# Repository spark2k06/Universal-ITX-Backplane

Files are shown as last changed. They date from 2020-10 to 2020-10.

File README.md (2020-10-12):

# Universal ITX BackPlane

This backplane is initially intended to be used with Sergey Kiselev's Micro8088 or xi8088 PC clones, among others system powered by x86 architecture. However, other old systems could also be developed using FPGAs built or adapted to ISA or PC / 104 type slots, plus other accessories based on these.

More information of this project in my Hackaday account: https://hackaday.io/project/175340-universal-itx-backplane

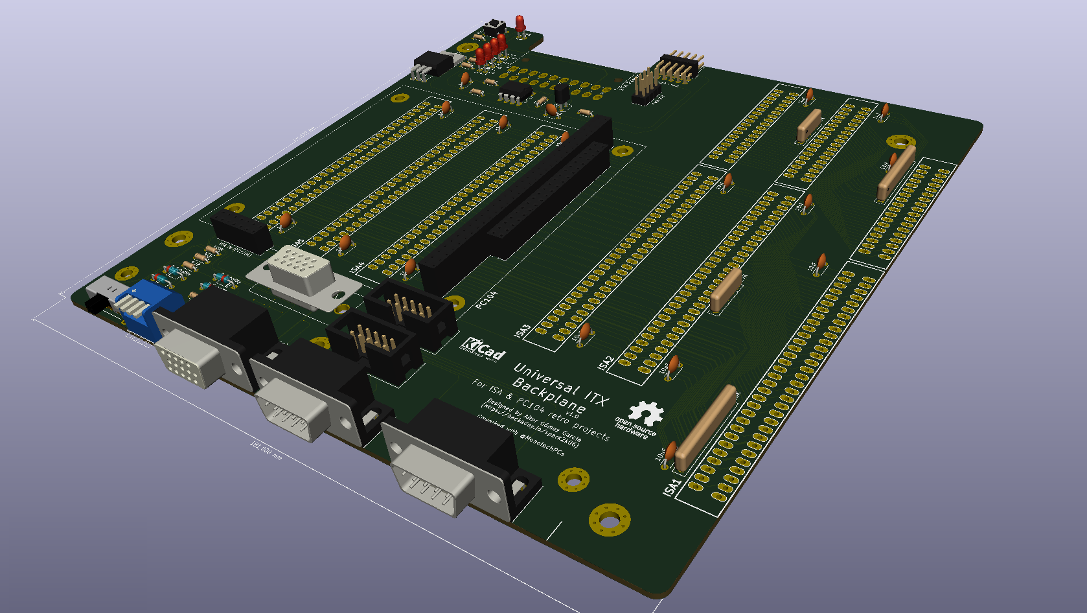
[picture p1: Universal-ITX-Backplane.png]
Jumpers


The PCB has several I / O connectors common to all projects:

* VGA + MonochromeVGA integrated
* 2 x DB9 ports to be used as serial ports or as joysticks

Additionally, each project can also add a Hat I / O board by adding other specific connectors. For example, an old PC based on a PC / 104 slot could add PS / 2 ports, IDE44 2.0mm connector to connect an external HD or CF, etc ... it must be taken into account that internally the Hat I / O board does not have of a lot of space, several holes have been placed to fasten it to the backplane.

Notice: The project is still in the prototype phase, the first version has not yet been tested.

# Version 1.0

First version of project

Coworked with @MonotechPCs (Twitter profile)

* 4 Layer Mini-ITX board
* 3 x ISA 8 / 16 bits slots
* 1 x PC104 8 / 16 bits slot
* 3 x ISA 8 bits slots
* I/O shield with MonochromeVGA integrated, VGA, and 2 x DB9 connectors

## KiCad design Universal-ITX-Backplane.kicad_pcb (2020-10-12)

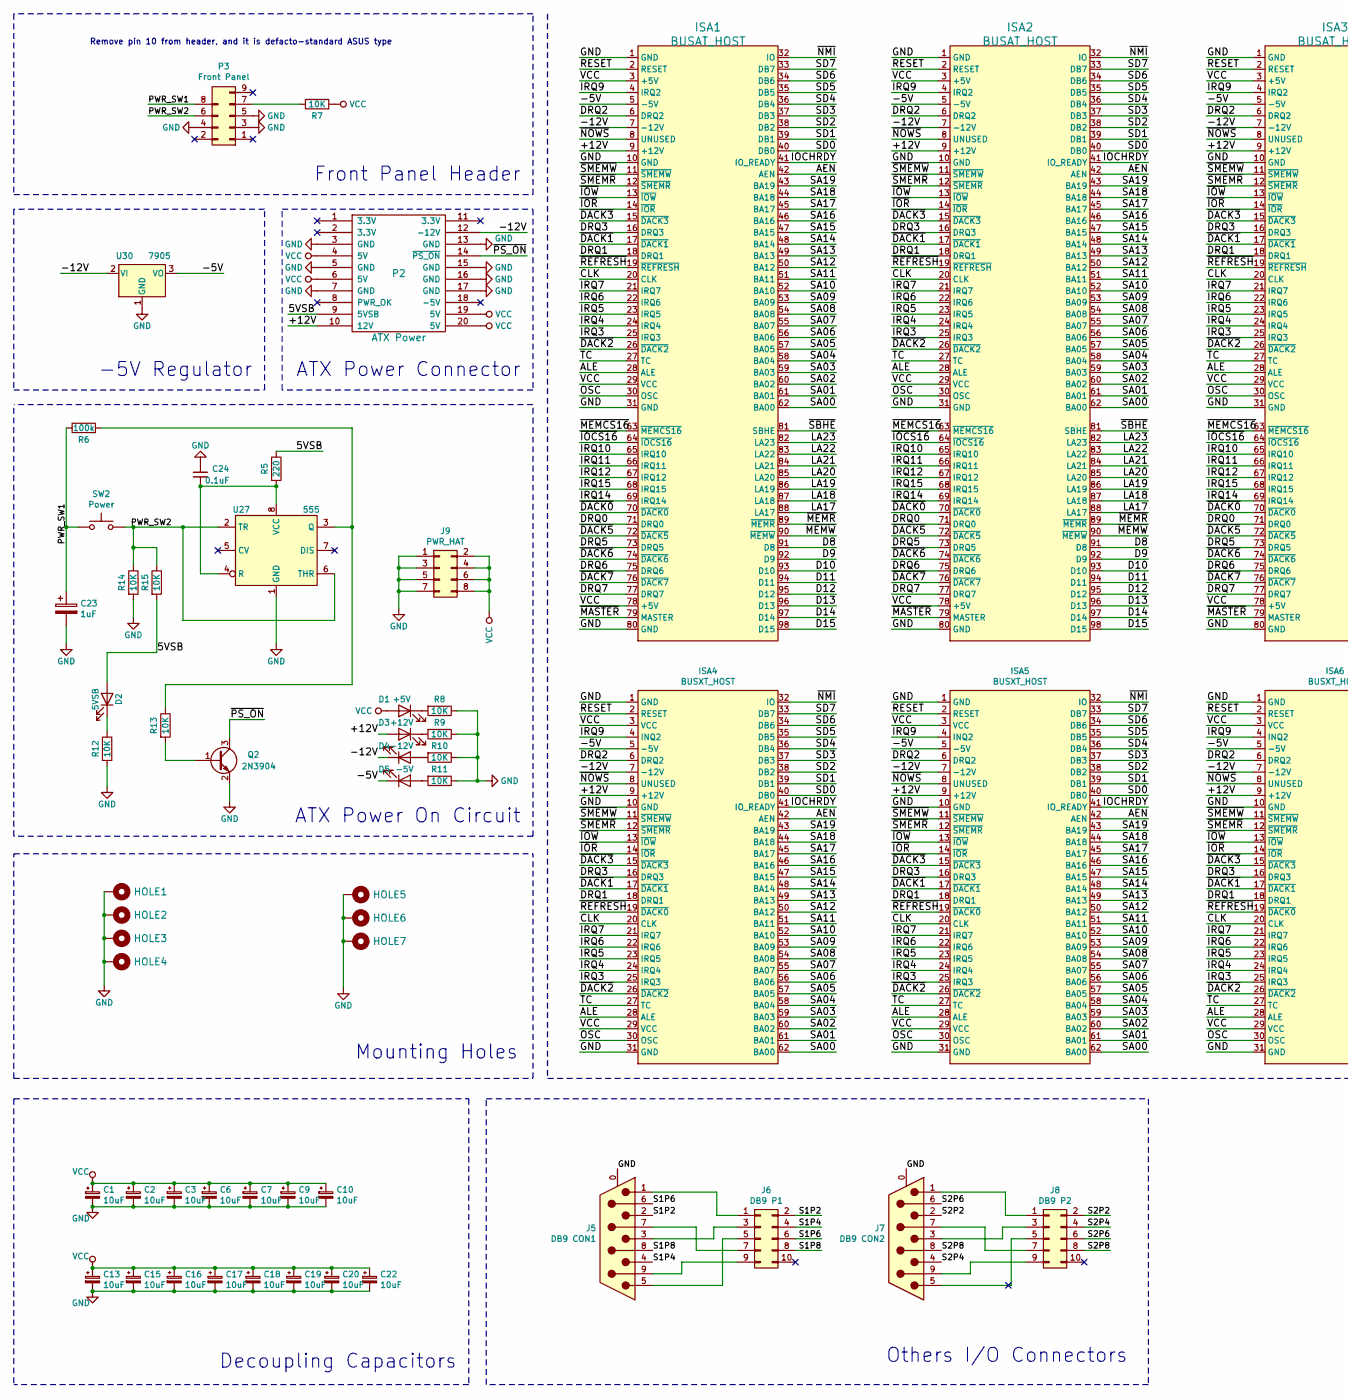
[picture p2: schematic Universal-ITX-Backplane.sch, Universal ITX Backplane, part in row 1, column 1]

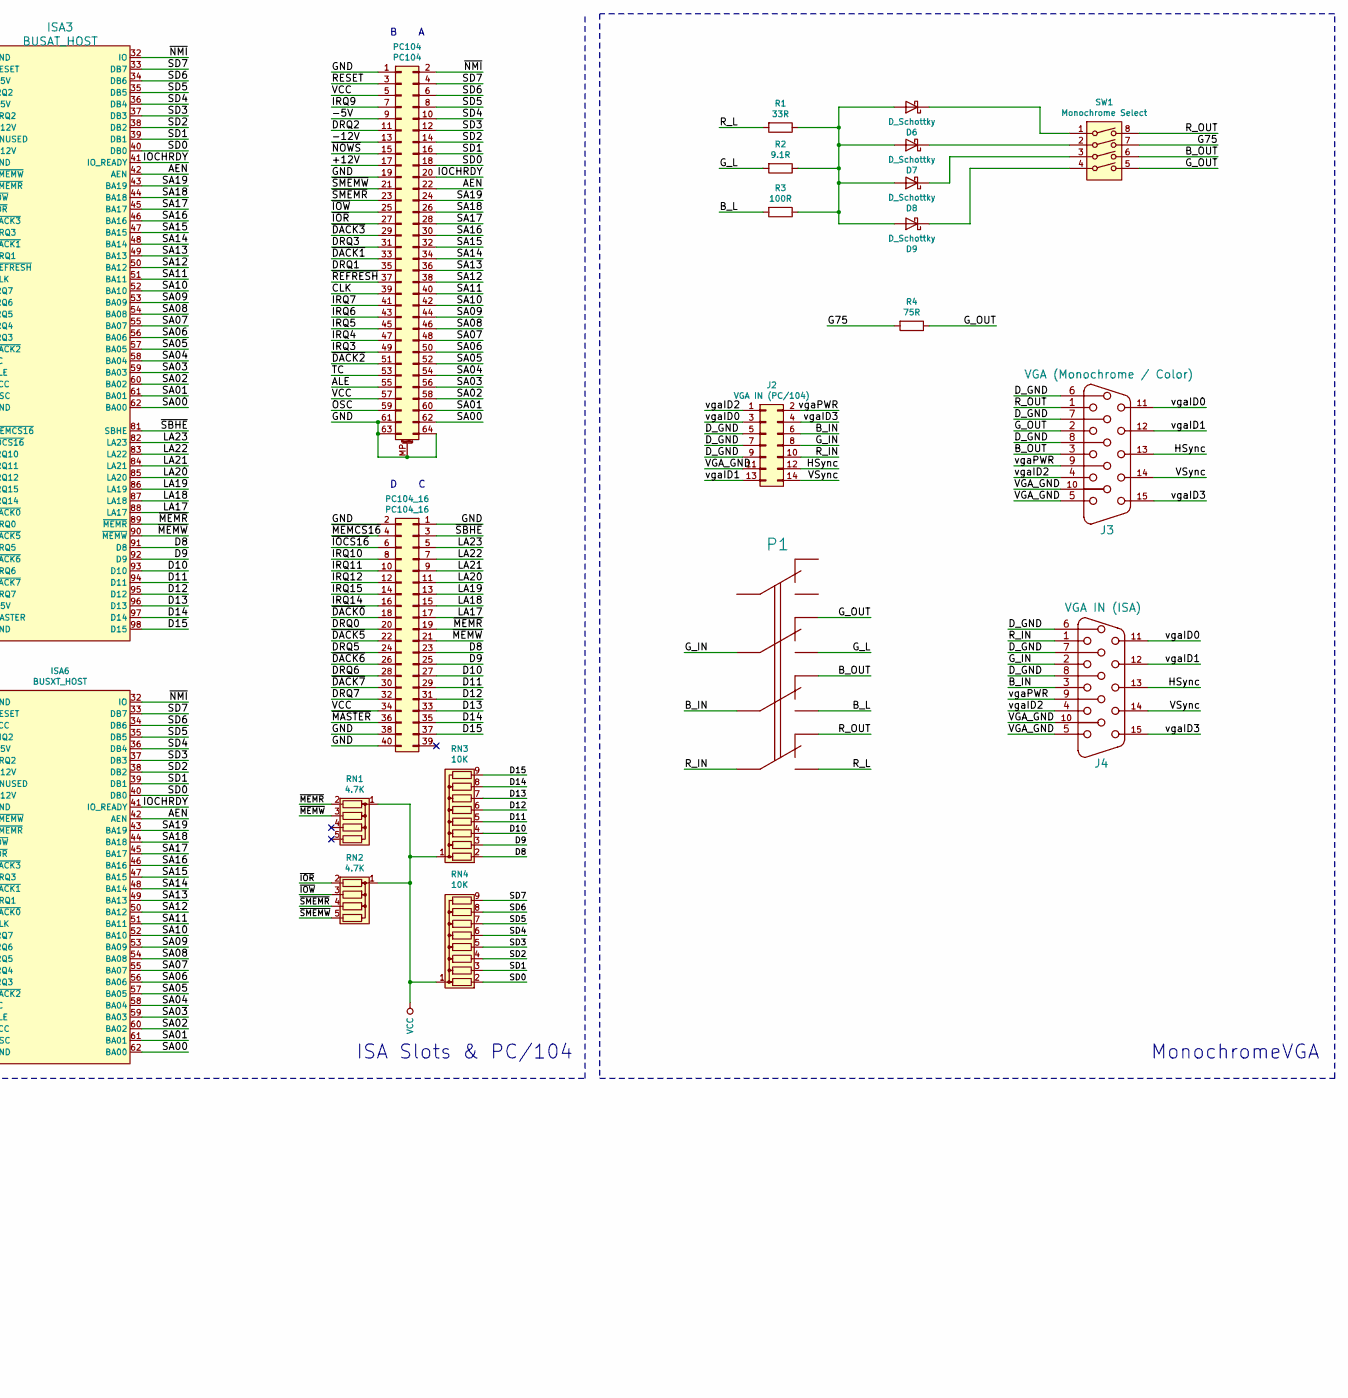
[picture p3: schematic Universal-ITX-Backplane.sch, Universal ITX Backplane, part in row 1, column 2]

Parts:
C1, C2, C3, C6, C7, C9, C10, C13, C15, C16, C17, C18, C19, C20, C22: 10uF; C_Disc_D4.3mm_W1.9mm_P5.00mm; LCSC P# C19702
C23: 1uF; C_Disc_D4.3mm_W1.9mm_P5.00mm; LCSC P# C28323
C24: 0.1uF; C_Disc_D4.3mm_W1.9mm_P5.00mm; LCSC P# C14663
D1: +5V; LED_D3.0mm; LCSC P# C84256
D2: 5VSB; LED_D3.0mm; LCSC P# C84256
D3: +12V; LED_D3.0mm; LCSC P# C84256
D4: -12V; LED_D3.0mm; LCSC P# C84256
D5: -5V; LED_D3.0mm; LCSC P# C84256
D6, D7, D8, D9: D_Schottky; D_DO-35_SOD27_P7.62mm_Horizontal
HOLE1, HOLE2, HOLE3, HOLE4: HOLE; MountingHole_4mm_Pad_Via
HOLE5, HOLE6, HOLE7: HOLE; MountingHole_3.2mm_M3_Pad_Via
ISA1, ISA2, ISA3: BUSAT_HOST; ISA16
ISA4, ISA5, ISA6: BUSXT_HOST; Conn_Edge_ISA8_Longpads
J2: VGA IN (PC/104); PinSocket_2x07_P2.54mm_Vertical
J3: VGA (Monochrome / Color); DSUB-15-HD_Female_Horizontal_P2.29x1.98mm_EdgePinOffset8.35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
J4: VGA IN (ISA); DSUB-15-HD_Female_Vertical_P2.29x1.98mm_MountingHoles
J5: DB9 CON1; DSUB-9_Male_Horizontal_P2.77x2.84mm_EdgePinOffset4.94mm_Hou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
J6: DB9 P1; IDC-Header_2x05_P2.54mm_Vertical
J7: DB9 CON2; DSUB-9_Male_Horizontal_P2.77x2.84mm_EdgePinOffset4.94mm_Hou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
J8: DB9 P2; IDC-Header_2x05_P2.54mm_Vertical
J9: PWR_HAT; PinHeader_2x04_P2.54mm_Vertical
P1: MONO <-> COLOR; SW-SK-42D01-G
P2: ATX Power; Molex_Mini-Fit_Jr_5569-20A2_2x10_P4.20mm_Horizontal
P3: Front Panel; PinHeader_2x05_P2.54mm_Horizontal
PC104: PC104; PC104_Platform
PC104_16: PC104_16; PinSocket_2x20_P2.54mm_Vertical
Q2: 2N3904; TO-92; LCSC P# C20526
R1: 33R; R_Axial_DIN0204_L3.6mm_D1.6mm_P5.08mm_Horizontal
R2: 9.1R; R_Axial_DIN0204_L3.6mm_D1.6mm_P5.08mm_Horizontal
R3: 100R; R_Axial_DIN0204_L3.6mm_D1.6mm_P5.08mm_Horizontal
R4: 75R; R_Axial_DIN0204_L3.6mm_D1.6mm_P5.08mm_Horizontal
R5: 220; R_Axial_DIN0204_L3.6mm_D1.6mm_P5.08mm_Horizontal; LCSC P# C17407
R6: 100k; R_Axial_DIN0204_L3.6mm_D1.6mm_P5.08mm_Horizontal; LCSC P# C17407
R7: 10K; R_Axial_DIN0204_L3.6mm_D1.6mm_P5.08mm_Horizontal
R8, R9, R10, R11, R12, R13, R14, R15: 10K; R_Axial_DIN0204_L3.6mm_D1.6mm_P5.08mm_Horizontal; LCSC P# C17407
RN1, RN2: 4.7K; R_Array_SIP5
RN3, RN4: 10K; R_Array_SIP9
SW1: Monochrome Select; SW_DIP_SPSTx04_Piano_10.8x11.72mm_W7.62mm_P2.54mm
SW2: Power; SW_PUSH_6mm; LCSC P# C128536
U27: 555; DIP-8_W7.62mm_LongPads; LCSC P# C7593
U30: 7905; TO220-3_Soldertab; LCSC P# C75505

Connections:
/5VSB: D2.2 (A), P2.9 (5VSB), R5.1, R15.2
/+12V: D3.2 (A), ISA1.9 (+12V), ISA2.9 (+12V), ISA3.9 (+12V), ISA4.9 (+12V), ISA5.9 (+12V), ISA6.9 (+12V), P2.10 (12V), PC104.17
/-5V: D5.1 (K), ISA1.5 (-5V), ISA2.5 (-5V), ISA3.5 (-5V), ISA4.5 (-5V), ISA5.5 (-5V), ISA6.5 (-5V), PC104.9, U30.3 (VO)
/-12V: D4.1 (K), ISA1.7 (-12V), ISA2.7 (-12V), ISA3.7 (-12V), ISA4.7 (-12V), ISA5.7 (-12V), ISA6.7 (-12V), P2.12 (-12V), PC104.13, U30.2 (VI)
/AEN: ISA1.42 (AEN), ISA2.42 (AEN), ISA3.42 (AEN), ISA4.42 (AEN), ISA5.42 (AEN), ISA6.42 (AEN), PC104.22
/ALE: ISA1.28 (ALE), ISA2.28 (ALE), ISA3.28 (ALE), ISA4.28 (ALE), ISA5.28 (ALE), ISA6.28 (ALE), PC104.55
/B_IN: J2.6, J4.3, P1.8
/B_L: P1.9, R3.2
/B_OUT: J3.3, P1.7, SW1.6
/CLK: ISA1.20 (CLK), ISA2.20 (CLK), ISA3.20 (CLK), ISA4.20 (CLK), ISA5.20 (CLK), ISA6.20 (CLK), PC104.39
/D8: ISA1.91 (D8), ISA2.91 (D8), ISA3.91 (D8), PC104_16.23, RN3.2 (R1)
/D9: ISA1.92 (D9), ISA2.92 (D9), ISA3.92 (D9), PC104_16.25, RN3.3 (R2)
/D10: ISA1.93 (D10), ISA2.93 (D10), ISA3.93 (D10), PC104_16.27, RN3.4 (R3)
/D11: ISA1.94 (D11), ISA2.94 (D11), ISA3.94 (D11), PC104_16.29, RN3.5 (R4)
/D12: ISA1.95 (D12), ISA2.95 (D12), ISA3.95 (D12), PC104_16.31, RN3.6 (R5)
/D13: ISA1.96 (D13), ISA2.96 (D13), ISA3.96 (D13), PC104_16.33, RN3.7 (R6)
/D14: ISA1.97 (D14), ISA2.97 (D14), ISA3.97 (D14), PC104_16.35, RN3.8 (R7)
/D15: ISA1.98 (D15), ISA2.98 (D15), ISA3.98 (D15), PC104_16.37, RN3.9 (R8)
/DRQ0: ISA1.71 (DRQ0), ISA2.71 (DRQ0), ISA3.71 (DRQ0), PC104_16.20
/DRQ1: ISA1.18 (DRQ1), ISA2.18 (DRQ1), ISA3.18 (DRQ1), ISA4.18 (DRQ1), ISA5.18 (DRQ1), ISA6.18 (DRQ1), PC104.35
/DRQ2: ISA1.6 (DRQ2), ISA2.6 (DRQ2), ISA3.6 (DRQ2), ISA4.6 (DRQ2), ISA5.6 (DRQ2), ISA6.6 (DRQ2), PC104.11
/DRQ3: ISA1.16 (DRQ3), ISA2.16 (DRQ3), ISA3.16 (DRQ3), ISA4.16 (DRQ3), ISA5.16 (DRQ3), ISA6.16 (DRQ3), PC104.31
/DRQ5: ISA1.73 (DRQ5), ISA2.73 (DRQ5), ISA3.73 (DRQ5), PC104_16.24
/DRQ6: ISA1.75 (DRQ6), ISA2.75 (DRQ6), ISA3.75 (DRQ6), PC104_16.28
/DRQ7: ISA1.77 (DRQ7), ISA2.77 (DRQ7), ISA3.77 (DRQ7), PC104_16.32
/D_GND: J2.5, J2.7, J2.9, J3.6, J3.7, J3.8, J4.6, J4.7, J4.8
/G75: R4.2, SW1.7
/G_IN: J2.8, J4.2, P1.5
/G_L: P1.6, R2.2
/G_OUT: J3.2, P1.4, R4.1, SW1.5
/HSync: J2.12, J3.13, J4.13
/IOCHRDY: ISA1.41 (IO_READY), ISA2.41 (IO_READY), ISA3.41 (IO_READY), ISA4.41 (IO_READY), ISA5.41 (IO_READY), ISA6.41 (IO_READY), PC104.20
/IRQ3: ISA1.25 (IRQ3), ISA2.25 (IRQ3), ISA3.25 (IRQ3), ISA4.25 (IRQ3), ISA5.25 (IRQ3), ISA6.25 (IRQ3), PC104.49
/IRQ4: ISA1.24 (IRQ4), ISA2.24 (IRQ4), ISA3.24 (IRQ4), ISA4.24 (IRQ4), ISA5.24 (IRQ4), ISA6.24 (IRQ4), PC104.47
/IRQ5: ISA1.23 (IRQ5), ISA2.23 (IRQ5), ISA3.23 (IRQ5), ISA4.23 (IRQ5), ISA5.23 (IRQ5), ISA6.23 (IRQ5), PC104.45
/IRQ6: ISA1.22 (IRQ6), ISA2.22 (IRQ6), ISA3.22 (IRQ6), ISA4.22 (IRQ6), ISA5.22 (IRQ6), ISA6.22 (IRQ6), PC104.43
/IRQ7: ISA1.21 (IRQ7), ISA2.21 (IRQ7), ISA3.21 (IRQ7), ISA4.21 (IRQ7), ISA5.21 (IRQ7), ISA6.21 (IRQ7), PC104.41
/IRQ9: ISA1.4 (IRQ2), ISA2.4 (IRQ2), ISA3.4 (IRQ2), ISA4.4 (INQ2), ISA5.4 (INQ2), ISA6.4 (INQ2), PC104.7
/IRQ10: ISA1.65 (IRQ10), ISA2.65 (IRQ10), ISA3.65 (IRQ10), PC104_16.8
/IRQ11: ISA1.66 (IRQ11), ISA2.66 (IRQ11), ISA3.66 (IRQ11), PC104_16.10
/IRQ12: ISA1.67 (IRQ12), ISA2.67 (IRQ12), ISA3.67 (IRQ12), PC104_16.12
/IRQ14: ISA1.69 (IRQ14), ISA2.69 (IRQ14), ISA3.69 (IRQ14), PC104_16.16
/IRQ15: ISA1.68 (IRQ15), ISA2.68 (IRQ15), ISA3.68 (IRQ15), PC104_16.14
/LA17: ISA1.88 (LA17), ISA2.88 (LA17), ISA3.88 (LA17), PC104_16.17
/LA18: ISA1.87 (LA18), ISA2.87 (LA18), ISA3.87 (LA18), PC104_16.15
/LA19: ISA1.86 (LA19), ISA2.86 (LA19), ISA3.86 (LA19), PC104_16.13
/LA20: ISA1.85 (LA20), ISA2.85 (LA20), ISA3.85 (LA20), PC104_16.11
/LA21: ISA1.84 (LA21), ISA2.84 (LA21), ISA3.84 (LA21), PC104_16.9
/LA22: ISA1.83 (LA22), ISA2.83 (LA22), ISA3.83 (LA22), PC104_16.7
/LA23: ISA1.82 (LA23), ISA2.82 (LA23), ISA3.82 (LA23), PC104_16.5
/OSC: ISA1.30 (OSC), ISA2.30 (OSC), ISA3.30 (OSC), ISA4.30 (OSC), ISA5.30 (OSC), ISA6.30 (OSC), PC104.59
/PWR_SW1: C23.1, P3.8, R6.1, SW2.1
/PWR_SW2: P3.6, R14.1, R15.1, SW2.2, U27.2 (TR), U27.6 (THR)
/RESET: ISA1.2 (RESET), ISA2.2 (RESET), ISA3.2 (RESET), ISA4.2 (RESET), ISA5.2 (RESET), ISA6.2 (RESET), PC104.3
/R_IN: J2.10, J4.1, P1.11
/R_L: P1.12, R1.2
/R_OUT: J3.1, P1.10, SW1.8
/S1P2: J5.2, J6.2
/S1P4: J5.4, J6.4
/S1P6: J5.6, J6.6
/S1P8: J5.8, J6.8
/S2P2: J7.2, J8.2
/S2P4: J7.4, J8.4
/S2P6: J7.6, J8.6
/S2P8: J7.8, J8.8
/SA00: ISA1.62 (BA00), ISA2.62 (BA00), ISA3.62 (BA00), ISA4.62 (BA00), ISA5.62 (BA00), ISA6.62 (BA00), PC104.62
/SA01: ISA1.61 (BA01), ISA2.61 (BA01), ISA3.61 (BA01), ISA4.61 (BA01), ISA5.61 (BA01), ISA6.61 (BA01), PC104.60
/SA02: ISA1.60 (BA02), ISA2.60 (BA02), ISA3.60 (BA02), ISA4.60 (BA02), ISA5.60 (BA02), ISA6.60 (BA02), PC104.58
/SA03: ISA1.59 (BA03), ISA2.59 (BA03), ISA3.59 (BA03), ISA4.59 (BA03), ISA5.59 (BA03), ISA6.59 (BA03), PC104.56
/SA04: ISA1.58 (BA04), ISA2.58 (BA04), ISA3.58 (BA04), ISA4.58 (BA04), ISA5.58 (BA04), ISA6.58 (BA04), PC104.54
/SA05: ISA1.57 (BA05), ISA2.57 (BA05), ISA3.57 (BA05), ISA4.57 (BA05), ISA5.57 (BA05), ISA6.57 (BA05), PC104.52
/SA06: ISA1.56 (BA06), ISA2.56 (BA06), ISA3.56 (BA06), ISA4.56 (BA06), ISA5.56 (BA06), ISA6.56 (BA06), PC104.50
/SA07: ISA1.55 (BA07), ISA2.55 (BA07), ISA3.55 (BA07), ISA4.55 (BA07), ISA5.55 (BA07), ISA6.55 (BA07), PC104.48
/SA08: ISA1.54 (BA08), ISA2.54 (BA08), ISA3.54 (BA08), ISA4.54 (BA08), ISA5.54 (BA08), ISA6.54 (BA08), PC104.46
/SA09: ISA1.53 (BA09), ISA2.53 (BA09), ISA3.53 (BA09), ISA4.53 (BA09), ISA5.53 (BA09), ISA6.53 (BA09), PC104.44
/SA10: ISA1.52 (BA10), ISA2.52 (BA10), ISA3.52 (BA10), ISA4.52 (BA10), ISA5.52 (BA10), ISA6.52 (BA10), PC104.42
/SA11: ISA1.51 (BA11), ISA2.51 (BA11), ISA3.51 (BA11), ISA4.51 (BA11), ISA5.51 (BA11), ISA6.51 (BA11), PC104.40
/SA12: ISA1.50 (BA12), ISA2.50 (BA12), ISA3.50 (BA12), ISA4.50 (BA12), ISA5.50 (BA12), ISA6.50 (BA12), PC104.38
/SA13: ISA1.49 (BA13), ISA2.49 (BA13), ISA3.49 (BA13), ISA4.49 (BA13), ISA5.49 (BA13), ISA6.49 (BA13), PC104.36
/SA14: ISA1.48 (BA14), ISA2.48 (BA14), ISA3.48 (BA14), ISA4.48 (BA14), ISA5.48 (BA14), ISA6.48 (BA14), PC104.34
/SA15: ISA1.47 (BA15), ISA2.47 (BA15), ISA3.47 (BA15), ISA4.47 (BA15), ISA5.47 (BA15), ISA6.47 (BA15), PC104.32
/SA16: ISA1.46 (BA16), ISA2.46 (BA16), ISA3.46 (BA16), ISA4.46 (BA16), ISA5.46 (BA16), ISA6.46 (BA16), PC104.30
/SA17: ISA1.45 (BA17), ISA2.45 (BA17), ISA3.45 (BA17), ISA4.45 (BA17), ISA5.45 (BA17), ISA6.45 (BA17), PC104.28
/SA18: ISA1.44 (BA18), ISA2.44 (BA18), ISA3.44 (BA18), ISA4.44 (BA18), ISA5.44 (BA18), ISA6.44 (BA18), PC104.26
/SA19: ISA1.43 (BA19), ISA2.43 (BA19), ISA3.43 (BA19), ISA4.43 (BA19), ISA5.43 (BA19), ISA6.43 (BA19), PC104.24
/SD0: ISA1.40 (DB0), ISA2.40 (DB0), ISA3.40 (DB0), ISA4.40 (DB0), ISA5.40 (DB0), ISA6.40 (DB0), PC104.18, RN4.2 (R1)
/SD1: ISA1.39 (DB1), ISA2.39 (DB1), ISA3.39 (DB1), ISA4.39 (DB1), ISA5.39 (DB1), ISA6.39 (DB1), PC104.16, RN4.3 (R2)
/SD2: ISA1.38 (DB2), ISA2.38 (DB2), ISA3.38 (DB2), ISA4.38 (DB2), ISA5.38 (DB2), ISA6.38 (DB2), PC104.14, RN4.4 (R3)
/SD3: ISA1.37 (DB3), ISA2.37 (DB3), ISA3.37 (DB3), ISA4.37 (DB3), ISA5.37 (DB3), ISA6.37 (DB3), PC104.12, RN4.5 (R4)
/SD4: ISA1.36 (DB4), ISA2.36 (DB4), ISA3.36 (DB4), ISA4.36 (DB4), ISA5.36 (DB4), ISA6.36 (DB4), PC104.10, RN4.6 (R5)
/SD5: ISA1.35 (DB5), ISA2.35 (DB5), ISA3.35 (DB5), ISA4.35 (DB5), ISA5.35 (DB5), ISA6.35 (DB5), PC104.8, RN4.7 (R6)
/SD6: ISA1.34 (DB6), ISA2.34 (DB6), ISA3.34 (DB6), ISA4.34 (DB6), ISA5.34 (DB6), ISA6.34 (DB6), PC104.6, RN4.8 (R7)
/SD7: ISA1.33 (DB7), ISA2.33 (DB7), ISA3.33 (DB7), ISA4.33 (DB7), ISA5.33 (DB7), ISA6.33 (DB7), PC104.4, RN4.9 (R8)
/TC: ISA1.27 (TC), ISA2.27 (TC), ISA3.27 (TC), ISA4.27 (TC), ISA5.27 (TC), ISA6.27 (TC), PC104.53
/VGA_GND: J2.11, J3.5, J3.10, J4.5, J4.10
/VSync: J2.14, J3.14, J4.14
/vgaID0: J2.3, J3.11, J4.11
/vgaID1: J2.13, J3.12, J4.12
/vgaID2: J2.1, J3.4, J4.4
/vgaID3: J2.4, J3.15, J4.15
/vgaPWR: J2.2, J3.9, J4.9
/~DACK0: ISA1.70 (~DACK0), ISA2.70 (~DACK0), ISA3.70 (~DACK0), PC104_16.18
/~DACK1: ISA1.17 (~DACK1), ISA2.17 (~DACK1), ISA3.17 (~DACK1), ISA4.17 (~DACK1), ISA5.17 (~DACK1), ISA6.17 (~DACK1), PC104.33
/~DACK2: ISA1.26 (~DACK2), ISA2.26 (~DACK2), ISA3.26 (~DACK2), ISA4.26 (~DACK2), ISA5.26 (~DACK2), ISA6.26 (~DACK2), PC104.51
/~DACK3: ISA1.15 (~DACK3), ISA2.15 (~DACK3), ISA3.15 (~DACK3), ISA4.15 (~DACK3), ISA5.15 (~DACK3), ISA6.15 (~DACK3), PC104.29
/~DACK5: ISA1.72 (~DACK5), ISA2.72 (~DACK5), ISA3.72 (~DACK5), PC104_16.22
/~DACK6: ISA1.74 (~DACK6), ISA2.74 (~DACK6), ISA3.74 (~DACK6), PC104_16.26
/~DACK7: ISA1.76 (~DACK7), ISA2.76 (~DACK7), ISA3.76 (~DACK7), PC104_16.30
/~IOCS16: ISA1.64 (~IOCS16), ISA2.64 (~IOCS16), ISA3.64 (~IOCS16), PC104_16.6
/~IOR: ISA1.14 (~IOR), ISA2.14 (~IOR), ISA3.14 (~IOR), ISA4.14 (~IOR), ISA5.14 (~IOR), ISA6.14 (~IOR), PC104.27, RN2.2 (R1)
/~IOW: ISA1.13 (~IOW), ISA2.13 (~IOW), ISA3.13 (~IOW), ISA4.13 (~IOW), ISA5.13 (~IOW), ISA6.13 (~IOW), PC104.25, RN2.3 (R2)
/~MASTER: ISA1.79 (MASTER), ISA2.79 (MASTER), ISA3.79 (MASTER), PC104_16.36
/~MEMCS16: ISA1.63 (~MEMCS16), ISA2.63 (~MEMCS16), ISA3.63 (~MEMCS16), PC104_16.4
/~MEMR: ISA1.89 (~MEMR), ISA2.89 (~MEMR), ISA3.89 (~MEMR), PC104_16.19, RN1.2 (R1)
/~MEMW: ISA1.90 (~MEMW), ISA2.90 (~MEMW), ISA3.90 (~MEMW), PC104_16.21, RN1.3 (R2)
/~NMI: ISA1.32 (IO), ISA2.32 (IO), ISA3.32 (IO), ISA4.32 (IO), ISA5.32 (IO), ISA6.32 (IO), PC104.2
/~NOWS: ISA1.8 (UNUSED), ISA2.8 (UNUSED), ISA3.8 (UNUSED), ISA4.8 (UNUSED), ISA5.8 (UNUSED), ISA6.8 (UNUSED), PC104.15
/~PS_ON: P2.14 (~PS_ON), Q2.3 (C)
/~REFRESH: ISA1.19 (~REFRESH), ISA2.19 (~REFRESH), ISA3.19 (~REFRESH), ISA4.19 (~DACK0), ISA5.19 (~DACK0), ISA6.19 (~DACK0), PC104.37
/~SBHE: ISA1.81 (SBHE), ISA2.81 (SBHE), ISA3.81 (SBHE), PC104_16.3
/~SMEMR: ISA1.12 (~SMEMR), ISA2.12 (~SMEMR), ISA3.12 (~SMEMR), ISA4.12 (~SMEMR), ISA5.12 (~SMEMR), ISA6.12 (~SMEMR), PC104.23, RN2.4 (R3)
/~SMEMW: ISA1.11 (~SMEMW), ISA2.11 (~SMEMW), ISA3.11 (~SMEMW), ISA4.11 (~SMEMW), ISA5.11 (~SMEMW), ISA6.11 (~SMEMW), PC104.21, RN2.5 (R4)
GND: C1.2, C2.2, C3.2, C6.2, C7.2, C9.2, C10.2, C13.2, C15.2, C16.2, C17.2, C18.2, C19.2, C20.2, C22.2, C23.2, C24.2, HOLE1.1, HOLE2.1, HOLE3.1, HOLE4.1, HOLE5.1, HOLE6.1, HOLE7.1, ISA1.1 (GND), ISA1.10 (GND), ISA1.31 (GND), ISA1.80 (GND), ISA2.1 (GND), ISA2.10 (GND), ISA2.31 (GND), ISA2.80 (GND), ISA3.1 (GND), ISA3.10 (GND), ISA3.31 (GND), ISA3.80 (GND), ISA4.1 (GND), ISA4.10 (GND), ISA4.31 (GND), ISA5.1 (GND), ISA5.10 (GND), ISA5.31 (GND), ISA6.1 (GND), ISA6.10 (GND), ISA6.31 (GND), J5.0 (PAD), J7.0 (PAD), J9.1, J9.3, J9.5, J9.7, P2.3 (GND), P2.5 (GND), P2.7 (GND), P2.13 (GND), P2.15 (GND), P2.16 (GND), P2.17 (GND), P3.3, P3.4, P3.5, PC104.1, PC104.19, PC104.61, PC104.63, PC104.64, PC104.MP (MountPin), PC104_16.1, PC104_16.2, PC104_16.38, PC104_16.40, Q2.2 (E), R8.1, R9.1, R10.1, R11.1, R12.2, R14.2, U27.1 (GND), U30.1 (GND)
unnamed: C24.1, R5.2, U27.4 (R), U27.8 (VCC)
unnamed: D1.1 (K), R8.2
unnamed: D2.1 (K), R12.1
unnamed: D3.1 (K), R9.2
unnamed: D4.2 (A), R10.2
unnamed: D5.2 (A), R11.2
unnamed: D6.1 (K), SW1.1
unnamed: D6.2 (A), D7.2 (A), D8.2 (A), D9.2 (A), R1.1, R2.1, R3.1
unnamed: D7.1 (K), SW1.2
unnamed: D8.1 (K), SW1.3
unnamed: D9.1 (K), SW1.4
unnamed: J5.1, J6.1
unnamed: J5.3, J6.3
unnamed: J5.5, J6.5
unnamed: J5.7, J6.7
unnamed: J5.9, J6.9
unnamed: J7.1, J8.1
unnamed: J7.3, J8.3
unnamed: J7.5, J8.5
unnamed: J7.7, J8.7
unnamed: J7.9, J8.9
unnamed: P3.7, R7.2
unnamed: Q2.1 (B), R13.2
unnamed: R6.2, R13.1, U27.3 (Q)
VCC: C1.1, C2.1, C3.1, C6.1, C7.1, C9.1, C10.1, C13.1, C15.1, C16.1, C17.1, C18.1, C19.1, C20.1, C22.1, D1.2 (A), ISA1.3 (+5V), ISA1.29 (VCC), ISA1.78 (+5V), ISA2.3 (+5V), ISA2.29 (VCC), ISA2.78 (+5V), ISA3.3 (+5V), ISA3.29 (VCC), ISA3.78 (+5V), ISA4.3 (VCC), ISA4.29 (VCC), ISA5.3 (VCC), ISA5.29 (VCC), ISA6.3 (VCC), ISA6.29 (VCC), J9.2, J9.4, J9.6, J9.8, P2.4 (5V), P2.6 (5V), P2.19 (5V), P2.20 (5V), PC104.5, PC104.57, PC104_16.34, R7.1, RN1.1 (common), RN2.1 (common), RN3.1 (common), RN4.1 (common)

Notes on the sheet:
ATX Power On Circuit
Remove pin 10 from header, and it is defacto-standard ASUS type
Front Panel Header
Decoupling Capacitors
ATX Power Connector
-5V Regulator
Mounting Holes
D C
B A
MonochromeVGA
ISA Slots & PC/104
Others I/O Connectors

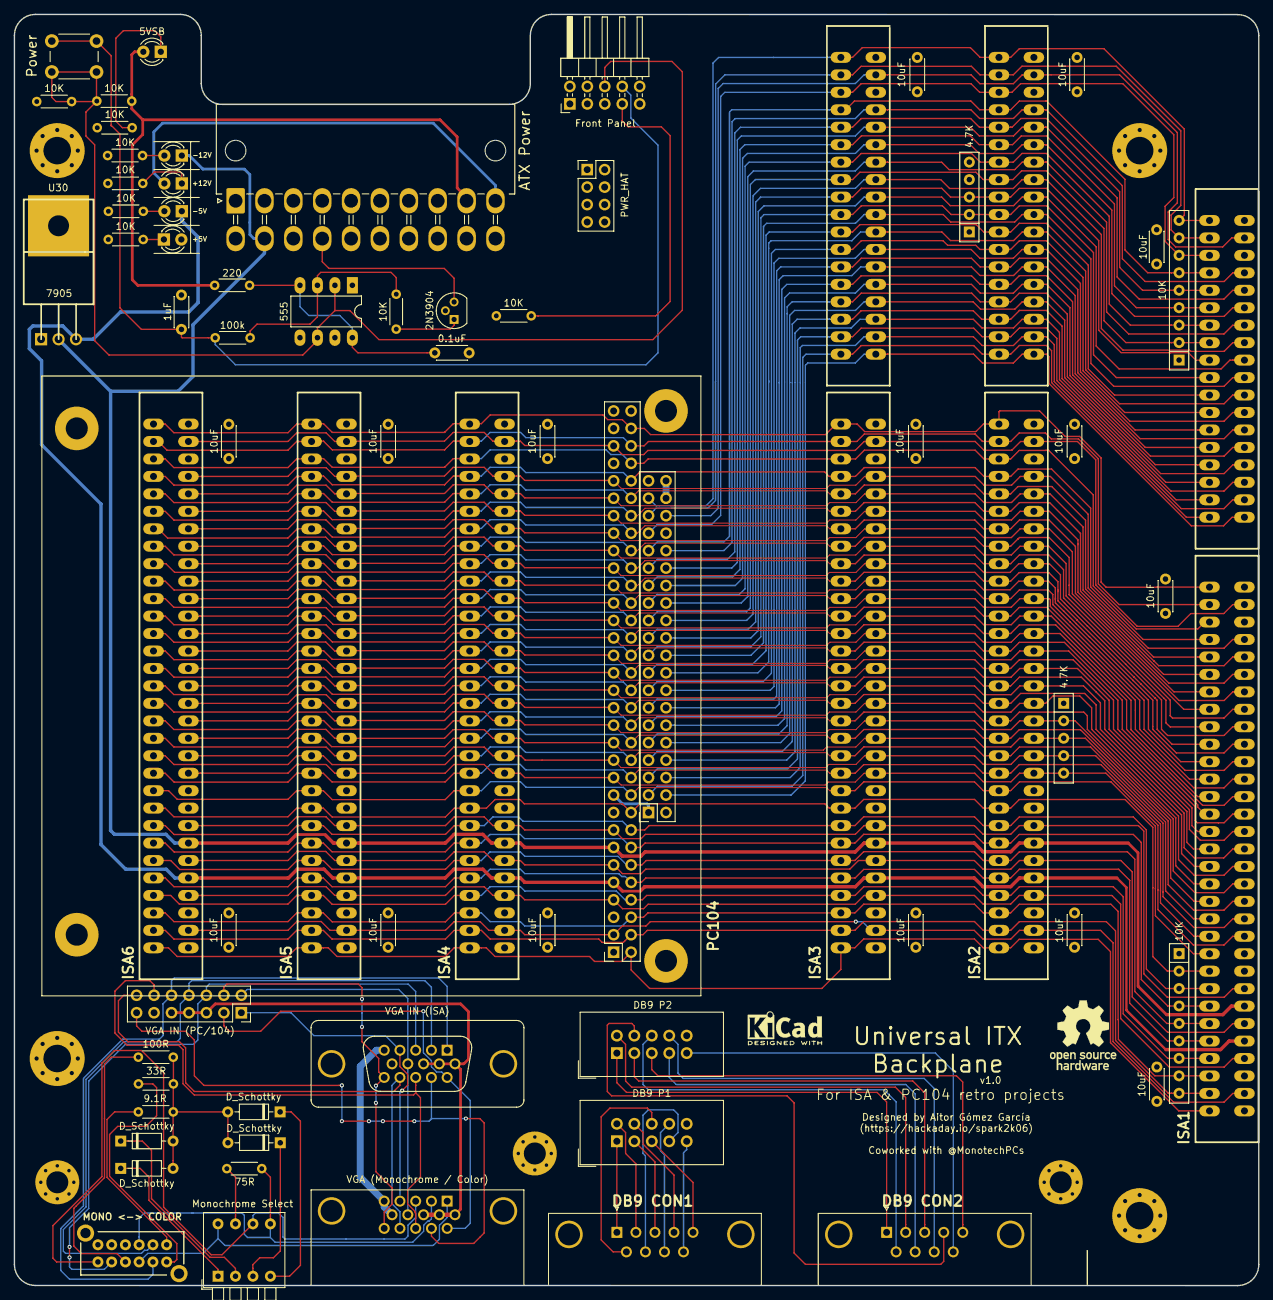
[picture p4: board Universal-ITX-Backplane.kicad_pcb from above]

Board: 4 copper layers, 181.0 x 184.9 mm, 76 parts (0 on the bottom side), 148 nets.

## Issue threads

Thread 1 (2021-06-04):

VGA signal

Dinth, 2021-06-04:
Hi. I hope you are well and thanks for designing such an amazing project!
If the board is still being developed, could i suggest adding an option to feed the VGA signal to the board using standard 2.54mm pins instead of DB-15 port? Many PC/104 boards with built in VGA have VGA output on pins instead of DB15 ports, so it would be much easier to connect that signal to the board using standard cables with 2.54mm connectors instead of making a custom 2.54mm to VGA cable

spark2k06, 2022-01-08:
Hi, thanks!

I no longer continue with the development of it ... but the VGA connector called VGA - PC/104 may help you for your proposal:

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

Closed 2022-01-14.

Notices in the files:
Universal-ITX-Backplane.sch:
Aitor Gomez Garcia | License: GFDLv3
